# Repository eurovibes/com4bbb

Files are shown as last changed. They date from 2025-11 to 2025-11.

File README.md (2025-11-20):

<!-- SPDX-FileCopyrightText: 2021 Benedikt Spranger <b.spranger@linutronix.de> -->
<!-- SPDX-License-Identifier: CERN-OHL-S-2.0 -->




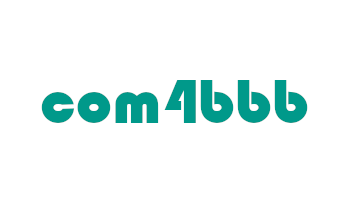
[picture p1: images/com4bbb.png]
com4bbb logo


# com4bbb - A RS485 / WiFi cape for Beaglebone Black

The Beaglobone Black is a TI Sitara AM3359 ARM Cortex-A8 CPU based
evaluation board with two 40pin 100mil pinsockets. These pinsockets
can be used for additional functionality boards called capes.
The com4bbb cape enhance the Beaglebone Black by a ESP32 based WiFi module
and a RS485 tranceiver.

## License rules

com4bbb is provided under the terms of the CERN-OHL-S license version 2 as
provided in the LICENSES/CERN-OHL-S-2.0 file.

Instead of adding license boilerplates to the individual files, com4bbb uses
SPDX license identifiers, which are machine parseable and considered legaly
equivalent.

The SPDX license identifier in com4bbb shall be added at the first possible
line in a file which can contain a comment. This is normally the first line
except for scripts. Scripts require the #!PATH_TO_INTERPRETER tag in the
first line; place the SPDX identifier into the second line.

The SPDX license identifier is added in form of a comment.

## Copyright and License

Copyright Benedikt Spranger 2021.
This source describes Open Hardware and is licensed under the CERNOHL-S v2.
You may redistribute and modify this source and make products using it
under the terms of the CERN-OHL-S v2
(https://ohwr.org/cern ohl s v2.txt ).
This source is distributed WITHOUT ANY EXPRESS OR IMPLIED
WARRANTY, INCLUDING OF MERCHANTABILITY, SATISFACTORY
QUALITY AND FITNESS FOR A PARTICULAR PURPOSE. Please see
the CERN-OHL-S v2 for applicable conditions.
Source location: https://github.com/eurovibes/com4bbb
As per CERN-OHL-S v2 section 4, should You produce hardware based
on this source, You must where practicable maintain the Source Location
visible on the external case of the com4bbb or other products you make using
this source.

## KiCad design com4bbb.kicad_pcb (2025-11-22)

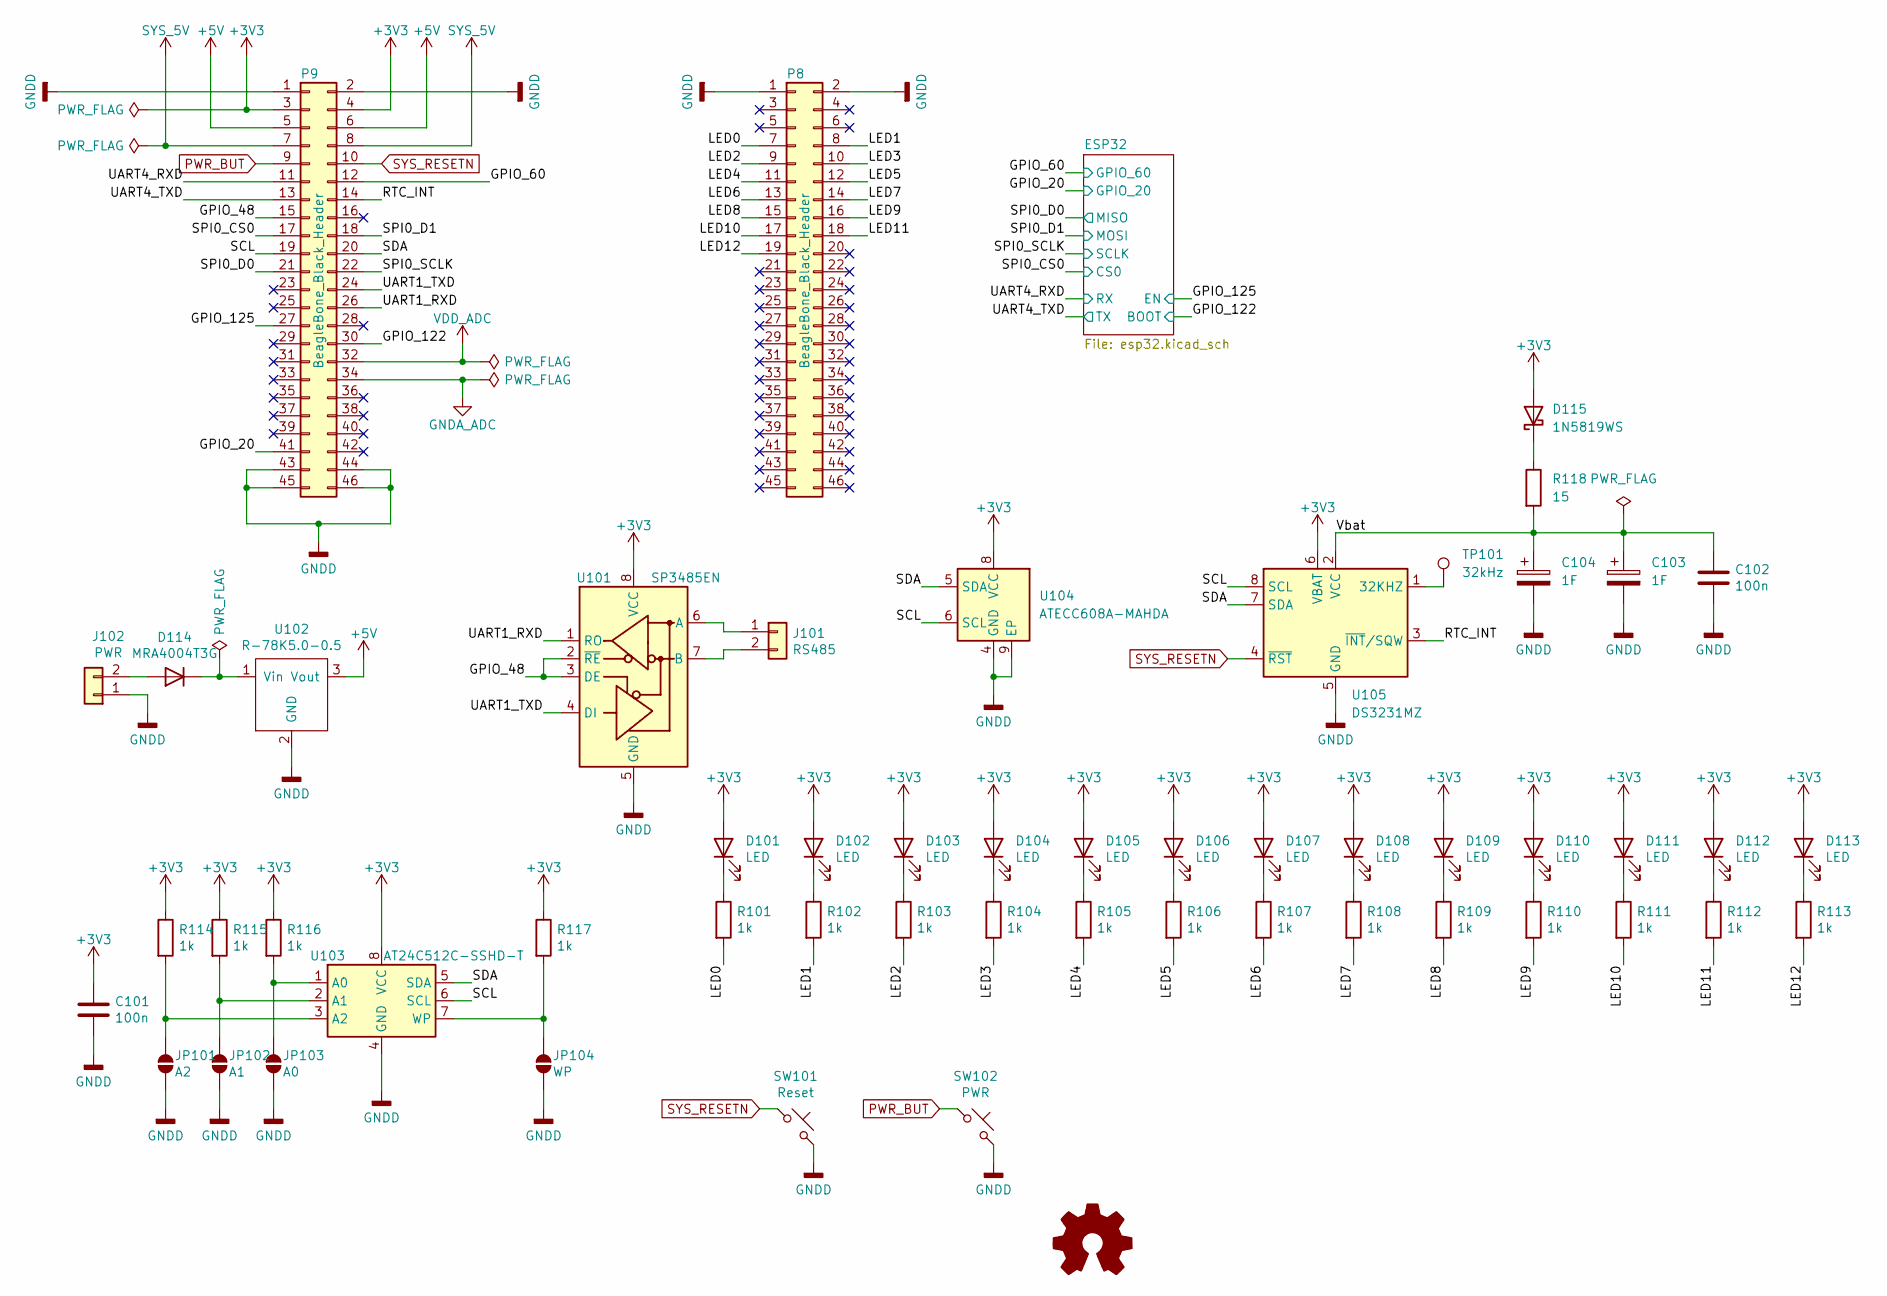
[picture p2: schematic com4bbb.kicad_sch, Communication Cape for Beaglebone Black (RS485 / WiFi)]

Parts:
C101, C102: 100n; C_0402_1005Metric; lcsc# C1525
C103, C104: 1F; CP_Radial_D8.0mm_P3.50mm
D101, D102, D103, D104, D105, D106, D107, D108, D109, D110, D111, D112, D113: LED; LED_0603_1608Metric; lcsc# C2286
D114: MRA4004T3G; D_SMA; lcsc# C40324
D115: 1N5819WS; D_SOD-323; lcsc# C191023
J101: RS485; TerminalBlock_WAGO_236-402_1x02_P5.00mm_45Degree; digikey# 2946-236-402-ND
J102: PWR; TerminalBlock_WAGO_236-402_1x02_P5.00mm_45Degree; digikey# 2946-236-402-ND
JP101: A2; SolderJumper-2_P1.3mm_Open_RoundedPad1.0x1.5mm
JP102: A1; SolderJumper-2_P1.3mm_Open_RoundedPad1.0x1.5mm
JP103: A0; SolderJumper-2_P1.3mm_Open_RoundedPad1.0x1.5mm
JP104: WP; SolderJumper-2_P1.3mm_Open_RoundedPad1.0x1.5mm
P8, P9: BeagleBone_Black_Header; PinHeader_2x23_P2.54mm_Vertical
R101, R102, R103, R104, R105, R106, R107, R108, R109, R110, R111, R112, R113, R114, R115, R116, R117: 1k; R_0402_1005Metric; lcsc# C11702
R118: 15; R_0805_2012Metric; lcsc# C17480
SW101: Reset; SW_PUSH_6mm
SW102: PWR; SW_PUSH_6mm
TP101: 32kHz; TestPoint_Pad_1.0x1.0mm
U101: SP3485EN; SOIC-8_3.9x4.9mm_P1.27mm; lcsc# C8963
U102: R-78K5.0-0.5; WPMDH1100xx1S
U103: AT24C512C-SSHD-T; SOIC-8_3.9x4.9mm_P1.27mm; lcsc# C6482
U104: ATECC608A-MAHDA; DFN-8-1EP_3x2mm_P0.5mm_EP1.3x1.5mm; lcsc# C17561150
U105: DS3231MZ; SOIC-8_3.9x4.9mm_P1.27mm; lcsc# C107410

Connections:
+3V3: C101.1, D101.2 (A), D102.2 (A), D103.2 (A), D104.2 (A), D105.2 (A), D106.2 (A), D107.2 (A), D108.2 (A), D109.2 (A), D110.2 (A), D111.2 (A), D112.2 (A), D113.2 (A), D115.2 (A), P9.3, P9.4, R114.1, R115.1, R116.1, R117.1, U101.8 (VCC), U103.8 (VCC), U104.8 (VCC), U105.6 (VBAT); also elsewhere on the board
+5V: P9.5, P9.6, U102.3 (Vout)
/GPIO_20: P9.41; also elsewhere on the board
/GPIO_48: P9.15, U101.2 (~RE), U101.3 (DE)
/GPIO_60: P9.12; also elsewhere on the board
/GPIO_122: P9.30; also elsewhere on the board
/GPIO_125: P9.27; also elsewhere on the board
/LED0: P8.7, R101.2
/LED1: P8.8, R102.2
/LED2: P8.9, R103.2
/LED3: P8.10, R104.2
/LED4: P8.11, R105.2
/LED5: P8.12, R106.2
/LED6: P8.13, R107.2
/LED7: P8.14, R108.2
/LED8: P8.15, R109.2
/LED9: P8.16, R110.2
/LED10: P8.17, R111.2
/LED11: P8.18, R112.2
/LED12: P8.19, R113.2
/RTC_INT: P9.14, U105.3 (~INT/SQW)
/SCL: P9.19, U103.6 (SCL), U104.6 (SCL), U105.8 (SCL)
/SDA: P9.20, U103.5 (SDA), U104.5 (SDA), U105.7 (SDA)
/SPI0_CS0: P9.17; also elsewhere on the board
/SPI0_D0: P9.21; also elsewhere on the board
/SPI0_D1: P9.18; also elsewhere on the board
/SPI0_SCLK: P9.22; also elsewhere on the board
/UART1_RXD: P9.26, U101.1 (RO)
/UART1_TXD: P9.24, U101.4 (DI)
/UART4_RXD: P9.11; also elsewhere on the board
/UART4_TXD: P9.13; also elsewhere on the board
/Vbat: C102.1, C103.1, C104.1, R118.2, U105.2 (VCC)
GNDA_ADC: P9.34
GNDD: C101.2, C102.2, C103.2, C104.2, J102.1, JP101.2 (B), JP102.2 (B), JP103.2 (B), JP104.2 (B), P8.1, P8.2, P9.1, P9.2, P9.43, P9.44, P9.45, P9.46, SW101.2, SW102.2, U101.5 (GND), U102.2 (GND), U103.4 (GND), U104.4 (GND), U104.9 (EP), U105.5 (GND); also elsewhere on the board
unnamed: D101.1 (K), R101.1
unnamed: D102.1 (K), R102.1
unnamed: D103.1 (K), R103.1
unnamed: D104.1 (K), R104.1
unnamed: D105.1 (K), R105.1
unnamed: D106.1 (K), R106.1
unnamed: D107.1 (K), R107.1
unnamed: D108.1 (K), R108.1
unnamed: D109.1 (K), R109.1
unnamed: D110.1 (K), R110.1
unnamed: D111.1 (K), R111.1
unnamed: D112.1 (K), R112.1
unnamed: D113.1 (K), R113.1
unnamed: D114.2 (A), J102.2
unnamed: D114.1 (K), U102.1 (Vin)
unnamed: D115.1 (K), R118.1
unnamed: J101.1, U101.6 (A)
unnamed: J101.2, U101.7 (B)
unnamed: JP101.1 (A), R114.2, U103.3 (A2)
unnamed: JP102.1 (A), R115.2, U103.2 (A1)
unnamed: JP103.1 (A), R116.2, U103.1 (A0)
unnamed: JP104.1 (A), R117.2, U103.7 (WP)
unnamed: TP101.1, U105.1 (32KHZ)
PWR_BUT: P9.9, SW102.1
SYS_5V: P9.7, P9.8
SYS_RESETN: P9.10, SW101.1, U105.4 (~RST)
VDD_ADC: P9.32

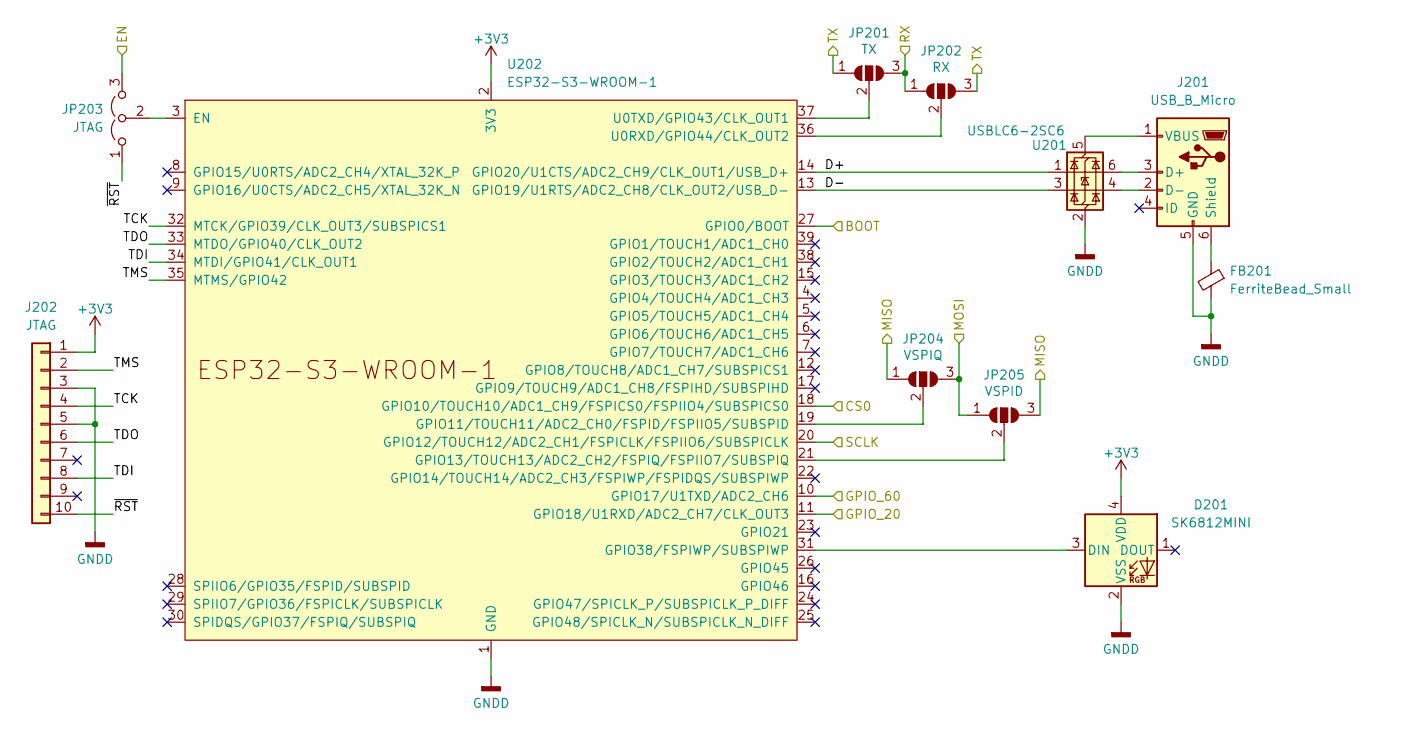
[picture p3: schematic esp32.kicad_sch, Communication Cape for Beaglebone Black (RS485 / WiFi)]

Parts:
D201: SK6812MINI; LED_SK6812MINI_PLCC4_3.5x3.5mm_P1.75mm; lcsc# C2922787
FB201: FerriteBead_Small; L_0402_1005Metric; lcsc# C14709
J201: USB_B_Micro; USB_Micro-B_Amphenol_10103594-0001LF_Horizontal; lcsc# C428495
J202: JTAG; Tag-Connect_TC2050-IDC-FP_2x05_P1.27mm_Vertical
JP201: TX; SolderJumper-3_P1.3mm_Open_RoundedPad1.0x1.5mm
JP202: RX; SolderJumper-3_P1.3mm_Open_RoundedPad1.0x1.5mm
JP203: JTAG; PinHeader_1x03_P2.54mm_Vertical
JP204: VSPIQ; SolderJumper-3_P1.3mm_Open_RoundedPad1.0x1.5mm
JP205: VSPID; SolderJumper-3_P1.3mm_Open_RoundedPad1.0x1.5mm
U201: USBLC6-2SC6; SOT-23-6; lcsc# C2687116
U202: ESP32-S3-WROOM-1; ESP32-S3-WROOM-1U; lcsc# C3013946

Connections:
+3V3: D201.4 (VDD), J202.1, U202.2 (3V3); also elsewhere on the board
/ESP32/D+: U201.1 (I/O1), U202.14 (GPIO20/U1CTS/ADC2_CH9/CLK_OUT1/USB_D+)
/ESP32/D-: U201.3 (I/O2), U202.13 (GPIO19/U1RTS/ADC2_CH8/CLK_OUT2/USB_D-)
/ESP32/TCK: J202.4, U202.32 (MTCK/GPIO39/CLK_OUT3/SUBSPICS1)
/ESP32/TDI: J202.8, U202.34 (MTDI/GPIO41/CLK_OUT1)
/ESP32/TDO: J202.6, U202.33 (MTDO/GPIO40/CLK_OUT2)
/ESP32/TMS: J202.2, U202.35 (MTMS/GPIO42)
/ESP32/~RST: J202.10, JP203.1 (A)
/GPIO_20: U202.11 (GPIO18/U1RXD/ADC2_CH7/CLK_OUT3); also elsewhere on the board
/GPIO_60: U202.10 (GPIO17/U1TXD/ADC2_CH6); also elsewhere on the board
/GPIO_122: U202.27 (GPIO0/BOOT); also elsewhere on the board
/GPIO_125: JP203.3 (B); also elsewhere on the board
/SPI0_CS0: U202.18 (GPIO10/TOUCH10/ADC1_CH9/FSPICS0/FSPIIO4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); also elsewhere on the board
/SPI0_D0: JP204.1 (A), JP205.3 (B); also elsewhere on the board
/SPI0_D1: JP204.3 (B), JP205.1 (A); also elsewhere on the board
/SPI0_SCLK: U202.20 (GPIO12/TOUCH12/ADC2_CH1/FSPICLK/FSPIIO6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); also elsewhere on the board
/UART4_RXD: JP201.3 (B), JP202.1 (A); also elsewhere on the board
/UART4_TXD: JP201.1 (A), JP202.3 (B); also elsewhere on the board
GNDD: D201.2 (VSS), FB201.2, J201.5 (GND), J202.3, J202.5, U201.2 (GND), U202.1 (GND), U202.40 (GND), U202.41 (GND); also elsewhere on the board
unnamed: D201.3 (DIN), U202.31 (GPIO38/FSPIWP/SUBSPIWP)
unnamed: J201.3 (D+), U201.6 (I/O1)
unnamed: J201.2 (D-), U201.4 (I/O2)
unnamed: FB201.1, J201.6 (Shield)
unnamed: J201.1 (VBUS), U201.5 (VBUS)
unnamed: JP201.2 (C), U202.37 (U0TXD/GPIO43/CLK_OUT1)
unnamed: JP202.2 (C), U202.36 (U0RXD/GPIO44/CLK_OUT2)
unnamed: JP203.2 (C), U202.3 (EN)
unnamed: JP204.2 (C), U202.19 (GPIO11/TOUCH11/ADC2_CH0/FSPID/FSPIIO5/S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)
unnamed: JP205.2 (C), U202.21 (GPIO13/TOUCH13/ADC2_CH2/FSPIQ/FSPIIO7/S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)

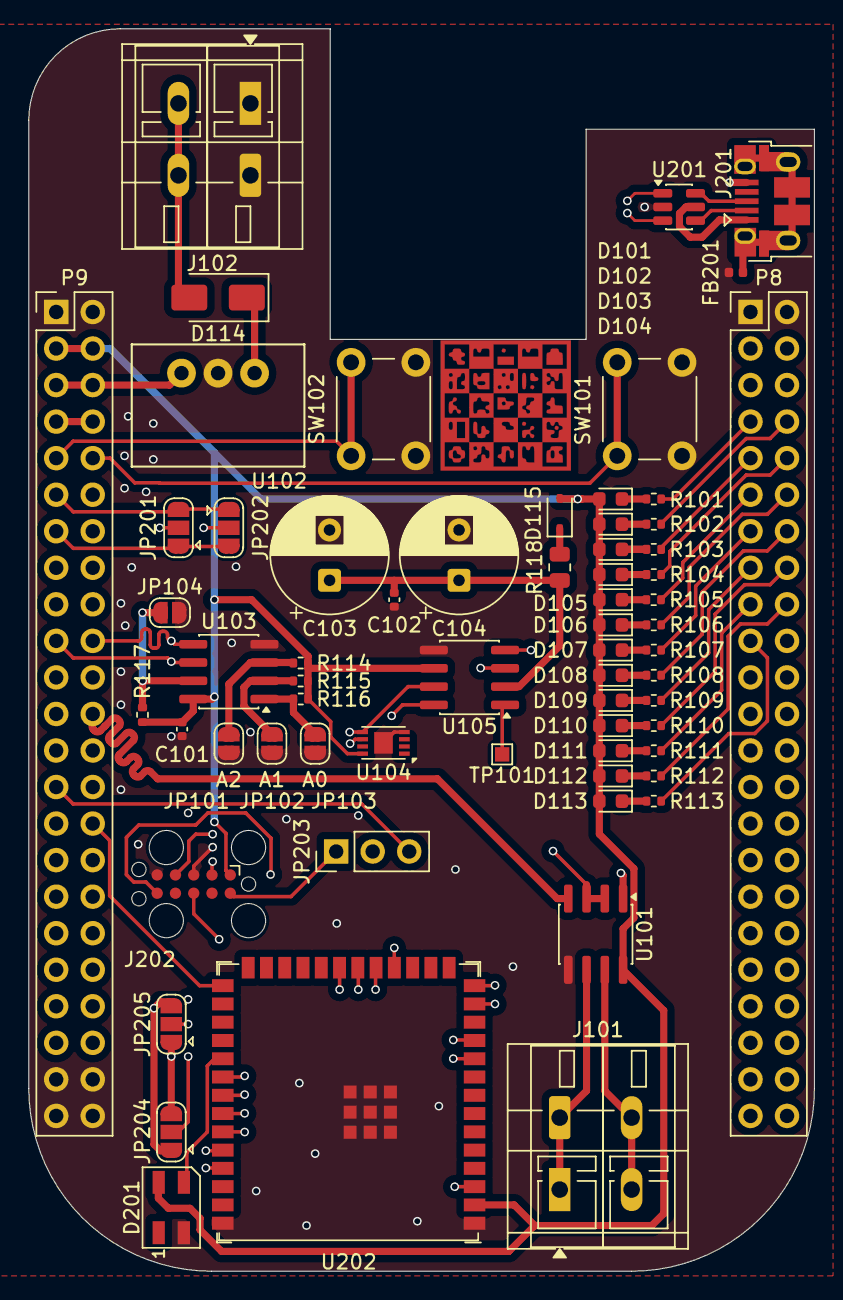
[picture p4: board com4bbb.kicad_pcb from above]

Board: 4 copper layers, 54.6 x 86.4 mm, 64 parts (0 on the bottom side), 76 nets.

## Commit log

2021-06-14 com4bbb: A RS485 / WiFi cape for the Beaglebone Black
    The Beaglobone Black is a TI Sitara AM3359 ARM Cortex-A8 CPU based
    evaluation board with two 40pin 100mil pinsockets. These pinsockets
    can be used for additional functionality boards called capes.
    The com4bbb cape enhance the Beaglebone Black by a ESP32 based WiFi module
    and a RS485 tranceiver.
    Initial commit.
    [com4bbb.kicad_pcb, com4bbb.sch]
2025-11-20 Add KiPlot configuration
    KiPlot is a KiCAD automatisation suite to generate Gerber files or generate
    a PDF from the schematic file.
    Add a KiPlot configuration to generate Gerber and schematic PDFs.
2025-11-20 Add github workflow
    Use a github workflow to automaticaly call KiPlot to generate a base
    board documentation.
2025-11-20 Add open hardware logo
    Change license to CERN-OHL-S v2, which can be found at
    https://ohwr.org/cern_ohl_s_v2.txt
    [com4bbb.sch]
2025-11-20 Connect missing boot pin
    The ESP32-wroom-32u module use IO0 to enter boot mode. In boot mode
    the device can be flashed. Connect IO0 to the Beagle Bone to be able
    to update firmware on demand.
    [com4bbb.kicad_pcb, com4bbb.sch]
2025-11-20 Update to KiCAD version 9
    [com4bbb.kicad_pcb, com4bbb.kicad_sch, com4bbb.sch]
2025-11-20 Convert symbol libraries to new KiCAD library format
2025-11-20 Move footprints into separate directory
2025-11-20 Move gerber zip archive into download directory
2025-11-21 Update to ESP32-S3-WROOM-1U
    [com4bbb.kicad_pcb, com4bbb.kicad_sch, esp32.kicad_sch]
2025-11-21 Rework order information
    [com4bbb.kicad_sch, esp32.kicad_sch]
2025-11-22 Add RTC and secure memory
    [com4bbb.kicad_pcb, com4bbb.kicad_sch]
2025-11-22 Change jumper position
    [com4bbb.kicad_pcb]

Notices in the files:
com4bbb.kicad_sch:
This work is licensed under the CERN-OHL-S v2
